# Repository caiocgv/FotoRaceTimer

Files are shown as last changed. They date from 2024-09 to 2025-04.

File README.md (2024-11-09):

# Foto Race Timer
## Intro
* Foto Race timer is a millisecond precision timer based on two RTC modules sycronized that will measure the time between an start and a finish.
* See specific folder for further details
## Peripherals 
#### Printer
* Recommended to use a printer to present results
* Using POS series printers is recomended due to mobility
#### Recommended apps for arduino usage
* [Android App](https://play.google.com/store/apps/details?id=com.phucynwa.mini.portable.bluetooth.pos.printer) 

* [IOS App](https://apps.apple.com/br/app/bluetooth-thermal-printer/id1599863946)

#### More details

* [Arduino Hardware](https://github.com/caiocgv/FotoRaceTimer/blob/main/Arduino/README.md)
* [ESP8266 Hardware](https://github.com/caiocgv/FotoRaceTimer/blob/main/Esp8266/readme.md)
* [WebApp](https://github.com/caiocgv/FotoRaceTimer/tree/main/Data_Script/Flask)

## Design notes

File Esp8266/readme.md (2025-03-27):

# Wifi Fotocell Model
Next evolution of fotocell, wifi capable for data handling and calibration.
## Hardware
* Based on ESP8266 for connectivity and greater stability.
* Internal recharble battery. 18650 1s li-ion.
* Data saved on flash memory, managed over wifi.
* Built-in laser.
* LDR for laser status.
* USB-C charging.
* Battery status indicator with 4 bar led.
* RTC calibration over wifi.
* Measured current consumption 0.225 Amps
## Schematic

## Bill of Materials
* NodeMCU ESP8266 12E
* LDR
* 10k pull down resistor
* LASER LED
* 18650 🔋 
* CHARGER MODULE
* STEP UP/DOWN MODULE
* VOLTAGE METER 
* DS1307 RTC

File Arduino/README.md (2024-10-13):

# Foto Race Timer
## Intro
This is the Arduino Based Setup.
## Hardware
* Arduino nano
* LDR for passage detection
* LED for status
* Laser Diode for feeding LDR
* SD card module for data storage
* RTC module for time keeping
* HC-06 for serial communication
## Software
Arduino software is pretty straight forward. The passage is detected due to the variation of the resistance on the LDR and the current time is registered. Millisecond is not native and is simulated by arduino based on second change. With few commands that the user can iterate
#### Delete
Read all stored data from previous passages and delete the file (the file cannot be recovered)
#### Read
Read all stored data
#### ID input
After every passage an ID (unique number or name) should be input in order for the time to be stored.
## Data Processing
#### Data handling 
Specific Apps for Android should be installed to register athlete IDs and Read/delete data. OTG cable needed.
* [Serial Bluetooth](https://play.google.com/store/apps/details?id=de.kai_morich.serial_bluetooth_terminal) write only
* [Serial USB](https://play.google.com/store/apps/details?id=de.kai_morich.serial_usb_terminal) write only
* [Arduino Droid](https://play.google.com/store/apps/details?id=name.antonsmirnov.android.arduinodroid2) write/read/delete
#### Data Processing
* With the data collected (ID, start, end) it should be imported with an custom EXCEL SHEET script that will handle the math and return the rank. 
* Python web app coming next release.
## Hardware schematic


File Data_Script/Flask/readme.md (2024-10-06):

# Flask Web App for Data Processing
## Capabilities
* Able to handle multistage or single stage races
* Save, export and upload athletes list
* Export results in PDF to be printed
* Share the results page for real time view
* Compatible with both Arduino and ESP based hardware
## Live site link


## Results link


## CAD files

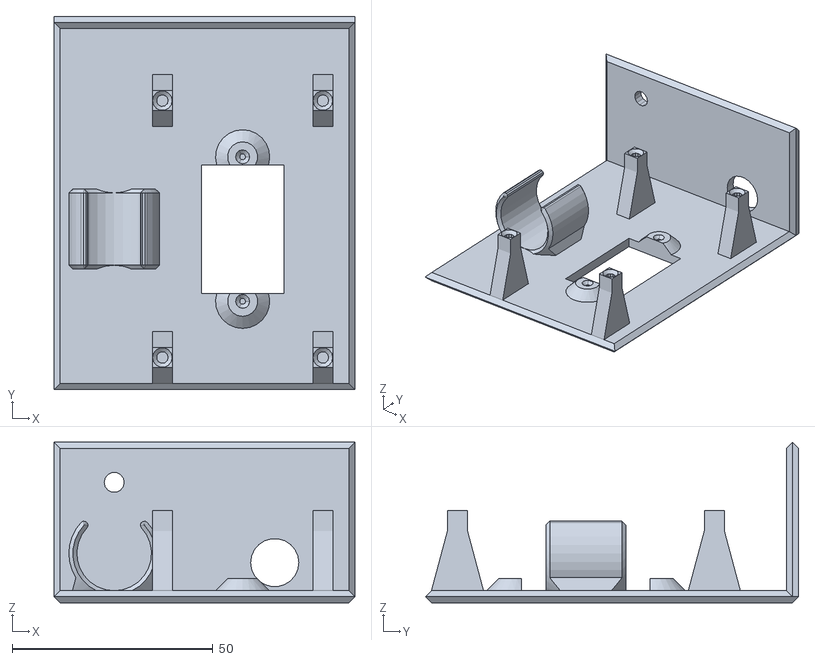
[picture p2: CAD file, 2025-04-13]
Esp8266/3d_case/ESP_case1.stl
75.0 x 93.0 x 40.0

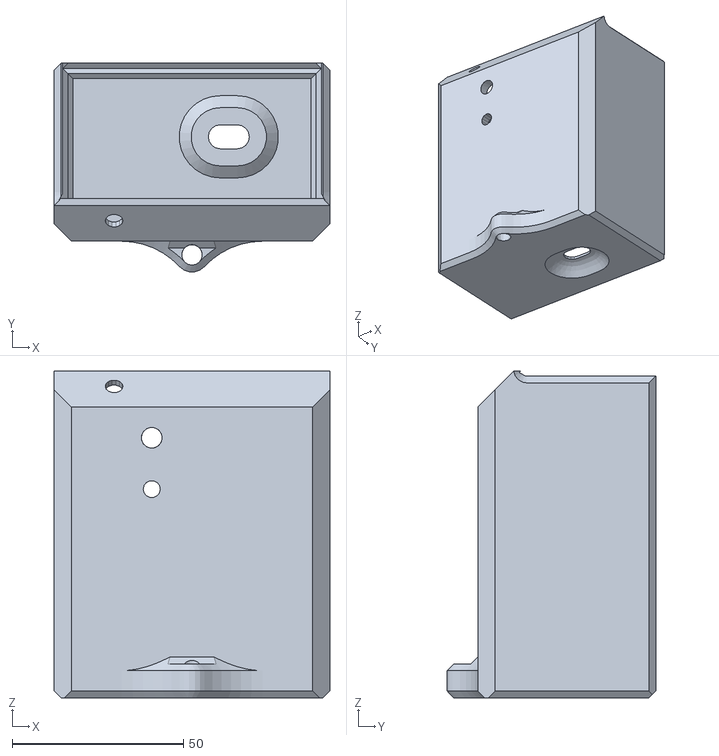
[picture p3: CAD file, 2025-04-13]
Esp8266/3d_case/ESP_case2.stl
80.5 x 60.9 x 95.5

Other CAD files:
Esp8266/3d_case/ESP_case1.ipt
Esp8266/3d_case/ESP_case2.ipt
Esp8266/3d_case/esp_case_assy.iam

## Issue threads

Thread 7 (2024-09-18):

Serial commands (read, delete) not working via app

caiocgv, 2024-09-18:
Works only via IDE serial monitor

caiocgv, 2024-09-20:
test arduino droid app

caiocgv, 2024-09-21:
Commands works on Arduino droid IDE via OTG cable. Should be enough for now.

caiocgv, 2024-09-22:
With larger files serial data is being chopped off

Closed 2024-09-22.

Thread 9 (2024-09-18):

RTC modules loses sync overtime

caiocgv, 2024-09-18:
Time difference should be measured before each use or should be automatically compensated

caiocgv, 2024-09-20:
measure how much is lost after a given time (preferably one week or one month) and then create a function to compensate the deviation.

caiocgv, 2024-09-21:
last resync start is 4.874 seconds ahead of finish

caiocgv, 2024-09-22:
with ESP based modules, create a routine to connect to the web and get the right time from the cloud.

caiocgv, 2024-10-09:
added calibration routine #48 to ease this issue, permanent solution still pending.

caiocgv, 2025-03-21:
partially solved with new esp8266 implementation. To be permanently solved by #81

Closed 2025-03-22.

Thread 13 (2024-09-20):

implement led laser to the main board instead of external light source

caiocgv, 2024-09-20:
[Laser Diode](https://www.google.com/search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)

caiocgv, 2024-10-14:
Implemented. Schematic updated commit `ec7ac83a72af018054427118ac5e502f9b33cd3e`

Closed 2024-10-14.

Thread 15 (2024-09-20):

millisecond calculation can be somewhat imprecise

caiocgv, 2024-09-20:

caiocgv, 2024-09-20:
how to test it's precision?

loss of second change has already been solved by #

caiocgv, 2024-09-20:
develop a routine which will use millis as the main time keeping source and then will compare to the time registered on rtc after a giver period

caiocgv, 2024-10-09:
Getting the deviation between fototimers suggests that the actual precision lies in the range of tenths of a second instead of millis. To be confirmed

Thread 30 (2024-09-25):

create workflow for autodeployment on pythonanywhere

caiocgv, 2024-09-25:

caiocgv, 2024-10-06:
Tested workflow didn't work. Currently deploying manually.

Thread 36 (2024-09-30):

create tripod design

caiocgv, 2024-09-30:
Can be designed to dig on the dirt

caiocgv, 2024-09-30:
Found a market version that could be usable, will be tested

caiocgv, 2024-10-09:
Tested marked version. Issue solved. [Link](https://www.mercadolivre.com.br/tripe-universal-com-nivel-laser-cameras-cel-120m-mmx-cinza-escuro/p/MLB29157670)

caiocgv, 2024-10-09:
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

Closed 2024-10-09.

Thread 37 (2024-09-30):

implement thread or servo motor for Fine alignment of laser

caiocgv, 2024-09-30:

caiocgv, 2024-10-05:
Brute force could be used to self align the laser. But the time spent on the self align routine could be an issue. TBD

caiocgv, 2024-10-09:
New tripod design solves alignment issue. Takes too short to align to make any other solution viable. Closing this issue.
[Tripod link](https://www.mercadolivre.com.br/tripe-universal-com-nivel-laser-cameras-cel-120m-mmx-cinza-escuro/p/MLB29157670)

caiocgv, 2024-10-09:
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

Closed 2024-10-09.

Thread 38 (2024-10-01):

issue when printing via thermer app

caiocgv, 2024-10-01:
Pdf files open as blank

caiocgv, 2024-10-01:
[Android App](https://play.google.com/store/apps/details?id=com.phucynwa.mini.portable.bluetooth.pos.printer)

[IOS App](https://apps.apple.com/br/app/bluetooth-thermal-printer/id1599863946)

caiocgv, 2024-10-01:
With both apps listed here, everything seems to be fine

Closed 2024-10-01.

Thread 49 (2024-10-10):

Results page generates a bug if the server is offline

caiocgv, 2024-10-10:
Should check if the variables are available, if not redirect to "\" landing page

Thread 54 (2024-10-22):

start and finish fototimers should be inter changeable

caiocgv, 2024-10-22:
this means that the calibration should be automatically swaped via app. Consider that start time is the lowest and finish time is the highest

Closed 2024-10-24.

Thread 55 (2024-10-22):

Bug when registering new athletes

caiocgv, 2024-10-22:
Enduro flag always goes "on"

caiocgv, 2024-10-22:
And calibration blow away

caiocgv, 2024-10-24:
solved on #57

Closed 2024-10-24.

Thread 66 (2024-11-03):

Laser losing intensity over time

caiocgv, 2024-11-03:
live tests to be made after the system is ready.

caiocgv, 2025-04-10:
Laser gets hot and lose power. Workaround?

caiocgv, 2025-04-10:
Ultrassonic sensor could be a solution

caiocgv, 2025-04-13:
adjusted power source to 4.8v so now the laser can run for hours with optimal power output and little to no heat dissipation.

Closed 2025-04-13.

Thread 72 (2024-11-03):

Set delay to be the same 2s on firmware

caiocgv, 2024-11-03:

caiocgv, 2025-03-23:
Delay cannot be used anymore since wifi functions can get unstable with it. Using interval and millisecond to control timed functions instead.

caiocgv, 2025-04-13:
done in #61

Closed 2025-04-13.

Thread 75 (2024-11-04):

Start and finish times should be reordered if neeeded

caiocgv, 2024-11-04:

caiocgv, 2025-04-13:
check for file names is not necessary anymore, missmatch between atlete ID and which time came before should be enough

caiocgv, 2025-04-24:
calibration files still need to be device unique. If update time button is a solution, then calibration is not needed anymore

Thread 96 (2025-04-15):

file name should not be needed for time input

caiocgv, 2025-04-15:

caiocgv, 2025-04-17:
This raises some problems with calibration files. To solve this, times would have to match perfectly. Maybe update time button already solves this. TBC

caiocgv, 2025-04-24:
duplicated #75

Closed 2025-04-24.

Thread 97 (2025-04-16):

export and delete previous results before switching device modes

caiocgv, 2025-04-16:

caiocgv, 2025-04-23:
closing issue without solution due to download limitations. file download and delete should be done by user before proceeding

Closed 2025-04-23.

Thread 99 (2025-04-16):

wireless detection of racer

caiocgv, 2025-04-16:
[https://pt.aliexpress.com/item/1005007985763659.html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,scm-url:1007.40196.417130.0,pvid:bbb18e88-a2e5-4ca8-9eb5-ce0d442836a2,tpp_buckets:668%232846%238110%231995&pdp_ext_f=%7B%22order%22%3A%22304%22%2C%22eval%22%3A%221%22%2C%22sceneId%22%3A%2230050%22%7D&pdp_npi=4%40dis%21BRL%2110.25%2110.25%21%21%2112.08%2112.08%21%402101e9a217448273416577904ecf16%2112000043163890802%21rec%21BR%212679301528%21X&utparam-url=scene%3ApcDetailBottomMoreOtherSeller%7Cquery_from%3A](usb module for micro esp)

[https://pt.aliexpress.com/item/1005006228229085.html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,scm-url:1007.40196.417130.0,pvid:2f36bf63-1daa-42ac-b901-8a99d1a35698,tpp_buckets:668%232846%238112%231997&pdp_ext_f=%7B%22order%22%3A%2293%22%2C%22eval%22%3A%221%22%2C%22sceneId%22%3A%2230050%22%7D&pdp_npi=4%40dis%21BRL%21211.15%2171.79%21%21%21248.82%2184.60%21%402101e9a217448272727676274ecf16%2112000036372705136%21rec%21BR%212679301528%21XZ&utparam-url=scene%3ApcDetailTopMoreOtherSeller%7Cquery_from%3A](micro esp)

caiocgv, 2025-04-17:
Wifi based detection can be done with any wifi capable device with signal strength and ssid as base metrics. To be tested

caiocgv, 2025-04-21:
Mechanical switch can also be a solution.

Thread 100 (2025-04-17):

captive portal not working properly on many devices

caiocgv, 2025-04-17:
further investigation pending...

caiocgv, 2025-04-22:
improved on 7bbd7412b13c87cfb1066be2466bf1e0601c3322, still not ready

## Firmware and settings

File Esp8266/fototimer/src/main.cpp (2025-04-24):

#include <Arduino.h>
#include <ESP8266WebServer.h> 
#include <ESP8266WiFi.h>
#include <DNSServer.h>
#include <LittleFS.h>
#include <RTClib.h>

#define sensorPin A0

RTC_DS1307 rtc;

const char* ssid = "largada";  // SSID of your access point, change name as needed
const byte DNS_PORT = 53;           // Port for DNS server
DNSServer dnsS;                     // Create a DNSServer object

ESP8266WebServer server(80);        // Create a webserver object that listens for HTTP request on port 80
ESP8266WiFiClass Wifi;              // Create a Wifi object

String text, newText, tempo, strTime, id, mode = "Inicio/Fim"; // Initialize variables                

String reset_button = "<form action='/restart'> \
                        <button type='submit' style='width: 150px;'>Reiniciar Contagem Atual</button> \
                      </form>";

int seconds, sensorValue, range = 100; 
unsigned long sec_mill, previousMillis, interval = 100, start, finish; // Initialize variables for timing and sensor reading


void handle_root() {
  File file = LittleFS.open("/landingpage.html", "r");
  if (file) {
    String root = file.readString();
    root.replace("{{text}}", text); // Replace the placeholder with the text from the file
    root.replace("{{mode}}", mode); // Replace the placeholder with the mode
    
    if (mode == "Inicio/Fim") {
      root.replace("{{reset_button}}", "");
    } else {
      root.replace("{{reset_button}}", reset_button);
    }

    file.close();    
    server.send(200, "text/html", root);
  } else {
    server.send(500, "text/plain", "Failed to open file for reading");
  }
}


void recalibrar() {
  sensorValue = 0;
  sensorValue = analogRead(sensorPin);
  sensorValue = sensorValue - range;
}


void get_time(){
  DateTime now = rtc.now();
  int hora = now.hour();
  int minuto = now.minute();
  int segundo = now.second();
  int milisegundo = (millis() - sec_mill) % 1000;
  tempo = "<td>" + String(hora) + ":" + String(minuto) + ":" + String(segundo) + ":" + String(milisegundo) + "</td></tr>" + text;
  strTime = String(hora) + ":" + String(minuto) + ":" + String(segundo) + ":" + String(milisegundo);
  recalibrar();
}


void settings() {
  get_time(); // Get the current time from the RTC module
  File file = LittleFS.open("/settings_page.html", "r"); // Open the settings HTML file
  if (file) {
    String settings = file.readString(); // Read the content of the file
    file.close(); // Close the file
    settings.replace("{{tempo}}", strTime); // Replace the placeholder with the current time
    settings.replace("{{range}}", String(range)); // Replace the placeholder with the range value
    server.send(200, "text/html", settings); // Send the settings page to the client
  } else {
    server.send(500, "text/plain", "Failed to open file for reading"); // Send HTTP status 500 (Internal server error) and the content type of the response
  }
}


void FileWrite() {
  File file = LittleFS.open("/text.txt", "w"); // Open the file in write mode 
  if (file) {
    file.println(newText); // Write the text to the file
    file.close();
    newText = "";
  } else {
    server.send(500, "text/plain", "Failed to open file for writing"); // Send HTTP status 500 (Internal server error) and the content type of the response
  }
}


void handle_post() {
  if (server.hasArg("message")) { // Check if the POST request has the message parameter
    id = server.arg("message");
  }
  
  // Check if the mode is "Circuito Fechado" and both start and finish times are set
  if (mode == "Circuito Fechado" && start != 0 && finish != 0) { 
    float elapsedTime = (finish - start) / 1000.0;
    tempo = "<td>" + String(elapsedTime, 3) + "s</td></tr>" + text;
    start = 0;
  }

  if (tempo != "" && id != "") { // Check if the text is not empty      
    newText = "<tr><td>" + id + "</td>" + tempo;
    text = newText;
    tempo = "";
    id = "";
    FileWrite(); // Write the text to permanent memory
  }
  
  handle_root();
}


void FileRead() {
  if (LittleFS.exists("/text.txt")) {
    File file = LittleFS.open("/text.txt", "r");
    if (file) {
      String content = file.readString();
      text = content;
      file.close();
    } else {
      server.send(500, "text/plain", "Failed to open file for reading");
    }
  }
}


void FileDelete() {
  if (LittleFS.exists("/text.txt")) {
    if (LittleFS.remove("/text.txt")) {
      Serial.println("File deleted successfully");
    } else {
      Serial.println("Failed to delete file");
    }
  } else {
    Serial.println("File does not exist");
  }
  text = ""; // Clear the text
  handle_root(); // Display the updated text on the webpage
}


void FileDownload() {
  if (LittleFS.exists("/text.txt")) {
    File file = LittleFS.open("/text.txt", "r");
    if (file) {
      server.sendHeader("Content-Disposition", "attachment; filename=" + String(ssid) + ".txt");
      server.streamFile(file, "application/octet-stream");
      file.close();
    } else {
      server.send(500, "text/plain", "Failed to open file for reading");
    }
  } else {
    server.send(404, "text/plain", "File not found");
  }
  handle_root(); // Display the updated text on the webpage
}


void update_time() {
  if (server.hasArg("current-time")) { // Check if the POST request has the current-time parameter
    String time = server.arg("current-time");
    int hour = time.substring(0, 2).toInt();
    int minute = time.substring(3, 5).toInt();
    int second = time.substring(6, 8).toInt();
    rtc.adjust(DateTime(rtc.now().year(), rtc.now().month(), rtc.now().day(), hour, minute, second));
  }
  settings(); // Display the updated settings page
}


void setup() {
  pinMode(LED_BUILTIN, OUTPUT);

  if (!rtc.begin()) {
    Serial.println("Couldn't find RTC");
    while (1);
  }

  Serial.begin(9600);
  Wifi.softAP(ssid);               // Set the ESP8266 to Access Point mode
  Serial.println("Access Point mode enabled at IP: " + WiFi.softAPIP().toString());

  dnsS.start(DNS_PORT, "*", WiFi.softAPIP()); // Start the DNS server

  while (WiFi.softAPgetStationNum() == 0) { // Wait for a client to connect to the access point
    digitalWrite(LED_BUILTIN, HIGH);
    delay(500);
    digitalWrite(LED_BUILTIN, LOW);
    delay(500);
  }

  if (!LittleFS.begin()) { // Initialize LittleFS
    Serial.println("Failed to initialize LittleFS");
    while (1) {} // Stop the program if LittleFS initialization fails
  }

  recalibrar();

  server.serveStatic("/style.css", LittleFS, "/style.css"); // Serve the CSS file
  server.onNotFound(handle_root); // Handle requests to the root URL
  server.on("/", HTTP_GET, handle_root);
  server.on("/post", HTTP_POST, handle_post);
  server.on("/delete", HTTP_GET, FileDelete);
  server.on("/download", HTTP_GET, FileDownload);
  server.on("/settings", HTTP_GET, settings);
  server.on("/update_time", HTTP_POST, update_time);
  server.on("/start_finish", HTTP_GET, []() {
    mode = "Inicio/Fim";
    handle_root();
  });
  server.on("/round_course", HTTP_GET, []() {
    mode = "Circuito Fechado";
    tempo = "";
    handle_root();
  });
  server.on("/range_set", HTTP_POST, []() {
    if (server.hasArg("range")) { // Check if the POST request has the message parameter
    range = server.arg("range").toInt();    
    }
    settings();
  });
  server.on("/restart", HTTP_GET, []() {
    start = 0; // Restart the ESP8266
    tempo = "";
    handle_root();
  });
  server.begin(); // Start the server
  FileRead();
}


void loop(){
  dnsS.processNextRequest();  // Handle DNS requests
  server.handleClient();      // Handle client requests

  // check for stable wifi connection
  if (WiFi.softAPgetStationNum() == 0){
    digitalWrite(LED_BUILTIN, HIGH);
  }

  // emulate milliseconds on RTC module
  if (seconds != rtc.now().second()){
    seconds = rtc.now().second();
    sec_mill = millis();
  }

  // Leitura do sensor com intervalo de tempo sem bloqueio do código
  unsigned long currentMillis = millis();
  if (currentMillis - previousMillis >= interval) { // Verifica se o intervalo de leitura foi atingido
    previousMillis = currentMillis;
    interval = 100;    
    digitalWrite(LED_BUILTIN,LOW);
  
    if (analogRead(sensorPin) < sensorValue){ // Se a leitura do sensor for menor que o valor de referencia registra o tempo
      digitalWrite(LED_BUILTIN,HIGH);
      
      if (mode == "Inicio/Fim"){
        get_time();

      } else if (mode == "Circuito Fechado"){
        
        if (start == 0){
          start = millis();
        } else {
          finish = millis();          
        }
      }
      interval = 2000; // Aumenta o intervalo de leitura para evitar múltiplas leituras
    } else if (analogRead(sensorPin) > sensorValue + range * 2){ // Se a leitura do sensor for maior que o valor de referencia recalibra
      recalibrar();
    }
  }
}

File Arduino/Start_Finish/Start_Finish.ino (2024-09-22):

#include <SPI.h>
#include <SD.h>

File myFile;

#include "Wire.h"
#define DS1307_ADDRESS 0x68
#define sensorPin A3


int i = 0, sensorValue;
String tempo = "", ID = "";
byte zero = 0x00;
long starmil, segundos;
float endmil;
const unsigned int MAX_MESSAGE_LENGTH = 12;


byte ConverteParaBCD(byte val)
{
  // Converte o número de decimal para BCD
  return ( (val / 10 * 16) + (val % 10) );
}


byte ConverteparaDecimal(byte val)
{
  // Converte de BCD para decimal
  return ( (val / 16 * 10) + (val % 16) );
}


void recalibrar() {
  sensorValue = 0;
  for (i = 0; i < 10; i++) {
    sensorValue = sensorValue + analogRead(sensorPin);
  }
  sensorValue = sensorValue / 10 - 50;
  
  i = 0;
}


void Read() {
  myFile = SD.open("test.txt");
  if (myFile) {
    delay(10);
    Serial.println("READING FILE test.txt:");
    while (myFile.available()) {
      delay(20);
      Serial.write(myFile.read());
    }
    myFile.close();
  }
  else Serial.println("Nenhum arquivo disponível.");
}


void Delete() {
  myFile = SD.open("test.txt");
  if (myFile) {
    delay(10);
    Serial.println("READING FILE test.txt:");
    while (myFile.available()) {
      delay(20);
      Serial.write(myFile.read());
    }
    Serial.println(" ");
    SD.remove("test.txt");
    Serial.println("File test.txt DELETED");
  }
  else Serial.println("Nenhum arquivo disponível.");
}


void setup() {
  pinMode(10, OUTPUT);
  pinMode(A3, INPUT);
  Serial.begin(9600);
  Wire.begin();
  
  if (!SD.begin(5)) {
    Serial.println("initialization failed!");
    while (1);
  }

  recalibrar();
  Serial.println("SYSTEM READY!");
}


void loop() {
  Wire.beginTransmission(DS1307_ADDRESS);
  Wire.write(zero);
  Wire.endTransmission();
  Wire.requestFrom(DS1307_ADDRESS, 1);
  endmil = ConverteparaDecimal(Wire.read());
  
  if (segundos != endmil) {
    starmil = millis();    
  }
  endmil = millis() - starmil;
  if (endmil > 1000){
    endmil = int(endmil) % 1000;
  }

  Wire.beginTransmission(DS1307_ADDRESS);
  Wire.write(zero);
  Wire.endTransmission();
  Wire.requestFrom(DS1307_ADDRESS, 3);
  segundos = ConverteparaDecimal(Wire.read());
  int minutos = ConverteparaDecimal(Wire.read());
  int horas = ConverteparaDecimal(Wire.read());

  //Serial.println(cont);
  if (analogRead(A3) < sensorValue) {
      digitalWrite(10, HIGH);
      
      tempo = String(horas) + ":";
      tempo = tempo + minutos + ":";
      tempo = tempo + segundos + ":";
      tempo = tempo + int(endmil);
      Serial.println(tempo);
      
      //escolha o delay necessário de acordo com a aplicação. (largada ou chegada)
      delay(500); // chegada
      //delay(5000); // largada
      recalibrar();
  }
  else {
    digitalWrite(10, LOW);
  }

  while (Serial.available() > 0)
  {
    static char message[MAX_MESSAGE_LENGTH];
    static unsigned int message_pos = 0;
    char inByte = Serial.read();

    if ( inByte != '\n' && (message_pos < MAX_MESSAGE_LENGTH - 1) )
    {
      message[message_pos] = inByte;
      message_pos++;
    }
    else
    {
      message[message_pos] = '\0';
      String msg = message;
      msg.toLowerCase();
    
      if (msg == "read") {
        Read();
      }
      else if (msg == "delete") {
        Delete();
      }
      else{
        ID = msg;
        Serial.println(msg);
      }
      message_pos = 0;
    }
  }
  
  if (tempo != "" and ID != ""){
     myFile = SD.open("test.txt", FILE_WRITE);
     myFile.println(tempo);
     myFile.println(ID);
     myFile.close();
     tempo = "";
     ID = "";
     Serial.println("Passagem computada com sucesso! Pronto para nova passagem.");
  }
}

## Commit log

2024-09-19 exported files from excel
    [Template_DH_nome.xlsm, Template_DH_num.xlsm]
2024-09-19 removed .bas file
    it will not be practical to keep .bas file out of excel sheet for now. Will be deprecated anyways when interface is moved to python.
    [Template_DH_num.xlsm]
2024-09-19 convert message to lowercase
    also only prints time and ID when both are available
2024-09-20 user commands are not case sensitive
2024-09-20 updated file structure
    [Template_DH_num.xlsm]
2024-09-20 Update README.md in arduino folder
2024-09-22 Update Template_DH_num.xlsm
    a few code corrections. to deal with multiple stages, user must enter the final digit as the stage number in order for the script to indentifiy. Special filters added to handle data. printer setup done
    [Template_DH_num.xlsm]
2024-09-22 add delay to avoid losing data
    [Start_Finish.ino]
2024-09-23 time sum function
    [Template_DH_num.xlsm]
2024-10-05 Create flask interface (#27)
    * Create main.py
    * Update main.py
    * Development in progress
    The application allows users to add new athletes via a form and view the list of athletes.
    It also provides a route to clear the list of athletes.
    The index.html template is used to display the list of athletes and the form for adding new athletes.
    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
    [Template_DH_num.xlsm]
2024-10-05 44 handle single stage races (#45)
    * single stage results handled
    minor bugs solved as well
    * minor bug fix
    everything working as expected
2024-10-09 Calib routine and categories edit (#48)
    * category edit added
    * Update index.html
    * Update index.html
    * Update index.html
    * Update index.html
    * Update index.html
    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
2024-10-13 Update arduino schematic
2024-10-13 Added schematic for ESP8266
2024-11-04 special results (#73)
    * special results
    special results feature added
    user can now create custom results by adding selected stages on each other.
    plus few bug fixes
    * Update results.html
    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
2025-03-22 Esp8266 firmware (#61)
    * first captive portal
    * adding variable text to captive portal
    * file handling and user posting info
    * updating app style and functionality
    * removing git ignore for platformIO and adding draft code
    * adding rtc functionality
    html adjusted to print time everytime a new post request is made.
    * rtc debug
    time being collected successfully with millisecond precision.
    * ldr working, rtc reading ok, with performance issues
    * still with issues
    + connection is ok
    + response time is fine
    - times are being doubled
    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
    [main.cpp]
2025-04-12 settings page on server and printing actual time of the device
2025-04-12 added update time functionality based on device time
2025-04-13 added latest 3d files
    [ESP_case1.ipt, ESP_case1.stl, ESP_case2.ipt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]
2025-04-15 removing debug print from flask app
2025-04-24 109 round course mode buggy (#111)
    * added button to restart counter
    * improved logic
    phantom readings won't get in the way as long as the ID isn't entered in the second passage
    [main.cpp]
